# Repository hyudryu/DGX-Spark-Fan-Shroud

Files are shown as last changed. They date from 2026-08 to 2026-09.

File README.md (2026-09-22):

# DGX-Spark-Fan-Shroud

Fan shrouds for NVIDIA GB10 systems, including the NVIDIA DGX Spark and partner platforms, for improved cooling performance on long workloads. Full STL/STEP files, electronics schematics, RP2040 firmware, and the FanController host application provide automatic temperature-based fan control.

The stock cooling on the DGX Spark can thermal-throttle during sustained multi-hour training or inference runs. This project adds a 3D-printed shroud that mounts a high-static-pressure Noctua industrialPPC fan over the heatsink, driven by a closed-loop controller that ramps fan speed with chip temperature — quiet at idle, full airflow under load.

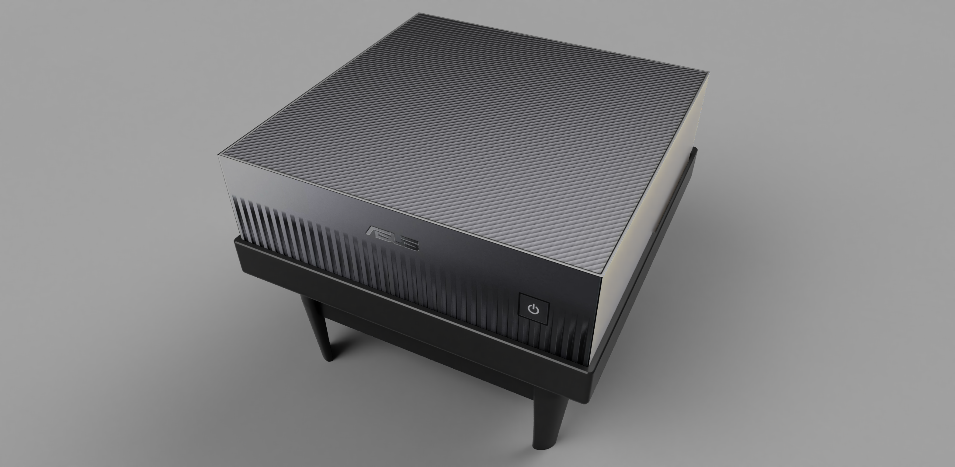
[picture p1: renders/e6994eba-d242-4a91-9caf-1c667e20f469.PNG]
Render of the ASUS Ascent GX10 with the fan shroud and stacking legs installed


## Cooling Results

### ASUS Ascent GX10

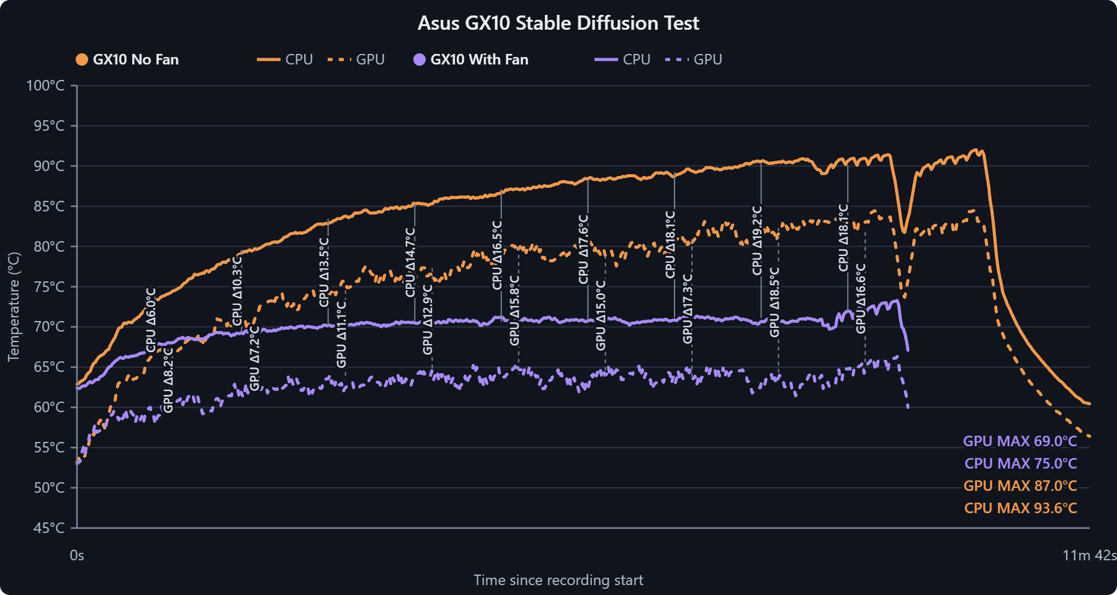
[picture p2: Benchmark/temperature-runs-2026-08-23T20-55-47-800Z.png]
ASUS Ascent GX10 Stable Diffusion temperature comparison with and without the fan shroud


In this roughly 12-minute Stable Diffusion run, the shroud reduced the recorded CPU peak from 93.6 °C to 75.0 °C and the GPU peak from 87.0 °C to 69.0 °C — reductions of 18.6 °C and 18.0 °C, respectively.

### NVIDIA DGX Spark

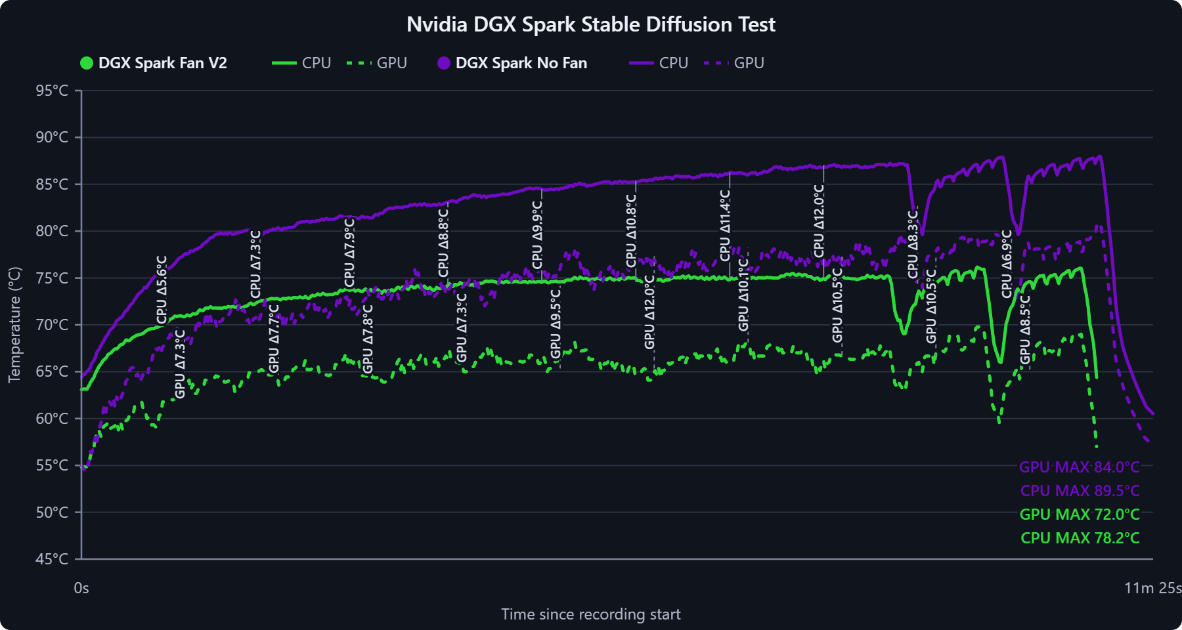
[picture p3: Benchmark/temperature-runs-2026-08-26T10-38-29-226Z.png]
NVIDIA DGX Spark Stable Diffusion temperature comparison with the V2 fan shroud


In this roughly 11-minute Stable Diffusion run, the V2 shroud reduced the recorded CPU peak from 89.5 °C to 78.2 °C and the GPU peak from 84.0 °C to 72.0 °C — reductions of 11.3 °C and 12.0 °C, respectively.

### Findings

The benchmark comparisons show lower CPU and GPU peak temperatures with the fan shroud installed. The ASUS Ascent GX10 result rounds to an approximately 20 °C reduction, while the NVIDIA DGX Spark V2 result and the other platform-specific models are approximately 10 °C reductions. Actual results vary with workload, ambient temperature, print fit, fan, and system vent layout.

| System | CPU peak reduction | GPU peak reduction | Approximate temperature drop |
| --- | ---: | ---: | ---: |
| ASUS Ascent GX10 | 18.6 °C measured | 18.0 °C measured | ~20 °C |
| NVIDIA DGX Spark | 11.3 °C measured | 12.0 °C measured | ~10 °C |
| Gigabyte AI TOP ATOM | ~10 °C | ~10 °C | ~10 °C |
| HP ZGX Nano | ~10 °C | ~10 °C | ~10 °C |
| Lenovo ThinkStation PGX | ~10 °C | ~10 °C | ~10 °C |
| MSI EdgeXpert | ~10 °C | ~10 °C | ~10 °C |

- **Approximately 20 °C lower peak temperatures** on the ASUS Ascent GX10.
- **Approximately 10 °C lower peak temperatures** on the other supported systems.
- Configured to **maintain ~80 °C under normal regular use** via the software fan curve.
- See `Benchmark/` for the interactive thermal benchmark graph and source comparisons.

## Compatibility

> **Compatibility note:** The design has been tested on the **ASUS Ascent GX10** and **NVIDIA DGX Spark**. In the charted tests, the NVIDIA DGX Spark reduction is about half the ASUS result because of its vent layout.
>
> Platform-specific files are also included for the **Gigabyte AI TOP ATOM**, **HP ZGX Nano**, **Lenovo ThinkStation PGX**, and **MSI EdgeXpert**. These variants have different chassis dimensions or vent layouts; verify fit and clearance before printing. Editable STEP files are included for inspection and adaptation.

## Repository Contents

| Path | Description |
| --- | --- |
| `3D Files/Asus Ascent GX10/` | ASUS shroud V2 plus shroud and stacking legs, in print-ready STL and editable STEP formats |
| `3D Files/Gigabyte AI Top Atom/` | Gigabyte fan/front shrouds plus shroud and stacking legs, in STL and STEP formats |
| `3D Files/HP ZGX Nano/` | HP fan/front shrouds plus shroud and stacking legs, in STL and STEP formats |
| `3D Files/Lenovo Thinkstation PGX/` | Lenovo fan/front shrouds plus shroud and stacking legs, in STL and STEP formats |
| `3D Files/MSI EdgeXpert/` | MSI fan/front shrouds plus shroud and stacking legs, in STL and STEP formats |
| `3D Files/Nvidia DGX Spark/` | NVIDIA fan/front shrouds plus shroud and stacking legs, in STL and STEP formats |
| `Benchmark/` | Interactive thermal benchmark graph plus PNG comparisons for quick viewing on GitHub |
| `firmware/` | MicroPython firmware for the RP2040-Zero and X9C103 digital potentiometer |
| `renders/` | Product renders of the shroud installed on supported systems |
| `software/` | FanController host application, systemd service, and tests |

## Bill of Materials

| Part | Purpose | Link |
| --- | --- | --- |
| Noctua industrialPPC fan | High static pressure / airflow through the shroud | https://amzn.to/4gRzM0Q |
| PWM controller | Generates the 25 kHz PWM signal that drives the fan | https://amzn.to/4pzXktr |
| Digital potentiometer | Sets the control voltage on the PWM controller from the microcontroller | https://amzn.to/4ffs8ft |
| RP2040-Zero | Receives host duty commands and drives the digital potentiometer | https://amzn.to/3TepWfD |

*(Links are Amazon affiliate links.)*

You will also need:

- Appropriate DC power for the fan (check your fan's rated voltage — industrialPPC variants are commonly 24 V)
- A USB-C cable capable of **data** transfer (for flashing the RP2040-Zero)
- Soldering iron and hookup wire, plus M3/M4 fasteners for the shroud legs

## How It Works

1. **Sense** — the control software polls the SoC temperature on the Spark (via `nvidia-smi` / tegrastats / hwmon).
2. **Decide** — a fan curve, PID loop, or hysteresis controller maps temperature to a target fan duty cycle.
3. **Actuate** — the firmware sets the digital potentiometer wiper, which drives the analog control input of the PWM controller, which in turn sets the fan's duty cycle.

This keeps the fan curve entirely under software control — you can tune it from a config file or CLI without touching hardware.

## Wiring

The X9C103 digital pot replaces the Owltree controller's onboard B10K potentiometer: remove (or ignore) the onboard pot and wire the X9C103's resistor terminals to its pads.

### RP2040-Zero → X9C103 Digital Pot

```
RP2040-Zero              X9C103 Digital Pot
────────────              ──────────────────
VBUS / 5V  ────────────── VCC
GND        ────────────── GND
GP29       ────────────── INC
GP28       ────────────── U/D
GP27       ────────────── CS
```

### RP2040-Zero → Owltree PWM Controller

```
RP2040-Zero              Owltree PWM Controller
────────────              ───────────────────────
VBUS / 5V  ────────────── VCC
GND        ────────────── GND
```

### Owltree B10K Pot Pads → X9C103

```
Owltree B10K Pot Pads     X9C103
─────────────────────     ──────
Outer pad 1  ──────────── VH
Center/wiper pad ──────── VW
Outer pad 2  ──────────── VL
```

### Full power layout

```
USB-C 5V
   │
   ├── RP2040-Zero VBUS / 5V
   ├── X9C103 VCC
   └── Owltree PWM Controller VCC

USB-C GND
   │
   ├── RP2040-Zero GND
   ├── X9C103 GND
   └── Owltree PWM Controller GND
```

### Full control layout

```
RP2040 GP29 ───────── X9C103 INC
RP2040 GP28 ───────── X9C103 U/D
RP2040 GP27 ───────── X9C103 CS

X9C103 VH ─────────── Owltree outer pot pad
X9C103 VW ─────────── Owltree center/wiper pad
X9C103 VL ─────────── Owltree outer pot pad
```

If the fan speed moves in the **opposite direction** from what the firmware expects, swap `VH` and `VL`. Do not swap the center `VW` connection.

### Important warnings

- **Check the Owltree VCC pad before wiring.** Only connect the Owltree `VCC` pad to `VBUS/5V` after confirming it is the controller's 5 V logic supply. Do **not** connect a 12 V fan-output or 12 V input rail to the RP2040.
- **Logic voltage.** The RP2040 GPIO pins output 3.3 V logic. Some X9C103 modules powered from 5 V may require a control-high voltage above 3.3 V — if the module does not respond reliably, use a 3.3-to-5 V logic-level shifter on `GP29 → INC`, `GP28 → U/D`, and `GP27 → CS`. Never feed 5 V into an RP2040 GPIO pin.
- **Isolate the original pot.** Remove or electrically isolate the Owltree's original B10K potentiometer before wiring the X9C103 to its pads.

## Flashing the RP2040-Zero

The included controller is [MicroPython firmware](firmware/main.py). Install
MicroPython on the RP2040-Zero, then copy the controller to the device as
`main.py` so it starts automatically at boot. See the
[firmware installation guide](firmware/README.md) for exact commands and the
USB serial protocol.

### Optional Arduino X9C103 test sketch

This standalone sketch drives the digital pot to one end stop, then back to
~50%. It can be used with the Arduino IDE to verify wiring before installing
the MicroPython controller:

```cpp
#include <Arduino.h>

constexpr uint8_t PIN_INC = 29;
constexpr uint8_t PIN_UD  = 28;
constexpr uint8_t PIN_CS  = 27;

void pulseIncrement() {
  digitalWrite(PIN_INC, LOW);
  delayMicroseconds(5);
  digitalWrite(PIN_INC, HIGH);
  delayMicroseconds(5);
}

void moveSteps(bool increase, int steps) {
  digitalWrite(PIN_CS, LOW);
  digitalWrite(PIN_UD, increase ? HIGH : LOW);
  delayMicroseconds(5);

  for (int i = 0; i < steps; ++i) {
    pulseIncrement();
  }

  digitalWrite(PIN_CS, HIGH);
  delay(10);
}

void setup() {
  pinMode(PIN_INC, OUTPUT);
  pinMode(PIN_UD, OUTPUT);
  pinMode(PIN_CS, OUTPUT);

  digitalWrite(PIN_INC, HIGH);
  digitalWrite(PIN_UD, LOW);
  digitalWrite(PIN_CS, HIGH);

  delay(1000);

  // Move fully toward the low end.
  moveSteps(false, 110);

  // Move approximately halfway up.
  moveSteps(true, 50);
}

void loop() {
  // Fan remains at the position selected during setup.
}
```

The X9C103 has ~100 positions; sending 110 steps guarantees it reaches the end stop without damage.

### First power-on procedure

1. Power the circuit **without** connecting a fan.
2. Confirm the RP2040 receives ~5 V on `VBUS`.
3. Confirm no RP2040 GPIO pin sees more than 3.3 V.
4. Measure the voltages on the Owltree potentiometer terminals and confirm `VH`, `VW`, and `VL` stay within the X9C103's permitted terminal-voltage range.
5. Connect the fan.
6. Flash the test firmware above and confirm the fan settles at roughly half speed.
7. If the speed direction is reversed, swap `VH` and `VL`.

## 3D Printing

- Choose the folder matching your system before slicing. Every platform folder keeps its print-ready STL and editable STEP files together.
- The revised `Shroud Leg` model is **65 mm tall overall**, 15 mm taller than the previous 50 mm version. Matching STL and STEP versions are included so the printable and editable models stay in sync.

### Recommended print settings

| Setting | Recommendation |
| --- | --- |
| Material | **PLA+ is suitable.** PETG, ASA/ABS, or a PC blend can also be used for greater temperature resistance. |
| Orientation | **Print each leg flat side down.** Keep the shroud in its supplied STL orientation. |
| Supports | **Tree/organic supports enabled** |
| Layer height | 0.2 mm |
| Walls | 4 |
| Infill | 40% or greater for the legs |

The leg (`Shroud Leg.stl`) supports the shroud against the chassis. Place its flat side directly on the build plate before slicing.

## Firmware & Software

The [`firmware/`](firmware/) directory contains the RP2040 digital-pot driver
and serial command interface. It starts at maximum cooling and returns to
maximum cooling if its host heartbeat disappears for five seconds.

The [`software/`](software/) directory contains the FanController application.
It discovers CPU and GPU temperature sensors, provides curve, PID, hysteresis,
and manual modes, and communicates with the firmware using `DUTY 0..255` and
`PING` commands over USB serial. See the
[software installation guide](software/README.md) to install the desktop UI
and headless systemd service.

## License

MIT — see [LICENSE](LICENSE).

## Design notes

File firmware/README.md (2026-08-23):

# Fan controller firmware

`main.py` is the MicroPython firmware for the RP2040-Zero and X9C103 digital
potentiometer described in the repository wiring guide. It accepts fan-duty
commands over the RP2040 USB serial connection and fails safe to maximum
cooling if communication with the host is lost.

## Install

1. Download the latest stable RP2 MicroPython `.uf2` from
   [micropython.org/download/RPI_PICO](https://micropython.org/download/RPI_PICO/).
2. Disconnect the RP2040-Zero, hold its `BOOT`/`BOOTSEL` button, reconnect its
   USB data cable, and release the button when the `RPI-RP2` drive appears.
3. Copy the MicroPython `.uf2` to `RPI-RP2`. The board will reboot and expose a
   USB serial port.
4. Install [mpremote](https://docs.micropython.org/en/latest/reference/mpremote.html)
   on the host and copy the controller program to the board:

   ```bash
   python3 -m pip install --user mpremote
   mpremote connect auto fs cp firmware/main.py :main.py
   mpremote connect auto reset
   ```

Run the `mpremote` commands from the repository root. If more than one
MicroPython device is attached, replace `auto` with the device path, for
example `/dev/ttyACM0`.

On boot, the firmware homes the X9C103 wiper and requests maximum fan speed.
Confirm that `DUTY 255` produces maximum airflow before relying on the
controller. If the direction is reversed, swap `VH` and `VL` as described in
the root wiring guide, or change `MAX_SPEED_AT_HIGH_TAP` in `main.py`.

## USB serial protocol

The USB serial connection uses line-delimited ASCII commands:

| Host command | Firmware response | Meaning |
| --- | --- | --- |
| `DUTY n` | `OK` | Set requested duty, where `n` is `0` through `255` |
| `PING` | `OK` | Keep the five-second safety watchdog alive |
| Invalid command | `ERR ...` | Command was rejected |

The firmware prints `BOOT` after startup and `RPM 0` once per second. RPM is
currently a placeholder because the fan tachometer is not connected.

If no valid `DUTY` or `PING` command arrives for five seconds, the firmware
forces `DUTY 255` until communication resumes.

## Quick serial test

Disconnect any host controller before opening the serial REPL, then run:

```bash
mpremote connect auto repl
```

Press `Ctrl-C` to interrupt `main.py`, then `Ctrl-D` to soft-reset and restart
it. A production host must send `PING` at least once every five seconds; the
FanController host software sends it once per second.

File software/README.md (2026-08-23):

# FanController host software

FanController runs on the DGX Spark, reads the available CPU and NVIDIA GPU
temperature sensors, applies a configurable control algorithm, and sends fan
duty commands to the RP2040 firmware over USB serial.

It provides:

- A GTK configuration and monitoring interface
- Curve, PID, hysteresis, and manual control modes
- CPU hwmon and `nvidia-smi` temperature discovery
- Temperature smoothing and duty slew limiting
- A headless systemd user service
- A mock serial device for configuration and testing without hardware
- Fail-safe maximum duty when no usable temperature is available

## Install

Flash the [RP2040 firmware](../firmware/README.md) first. Then, from this
directory, run:

```bash
./setup.sh
```

The setup script installs the GTK and serial dependencies, gives the current
user access to serial devices through the `dialout` group, installs the
application launcher, and enables the headless user service. Log out and back
in if the script adds you to `dialout`.

To install without enabling the service:

```bash
./setup.sh --no-enable
```

## Configure and run

Open the configuration interface from the desktop application menu or run:

```bash
python3 -m fancontroller --ui-only
```

Select the RP2040 serial port (normally `/dev/ttyACM0`), choose one or more
temperature sources, configure the desired control mode, and save. The
headless daemon reloads configuration changes automatically.

Useful commands:

```bash
python3 -m fancontroller --check
systemctl --user start fancontroller
systemctl --user status fancontroller
journalctl --user-unit fancontroller -f
```

Settings are stored in `~/.config/fancontroller/config.json`. Runtime state is
published atomically to `$XDG_STATE_HOME/fancontroller/state.json`, or
`~/.local/state/fancontroller/state.json` when `XDG_STATE_HOME` is unset.
This local state file is optional integration data; the controller does not
require a dashboard, server, network connection, or any other application.

## Test

The unit tests use only the Python standard library:

```bash
python3 -m unittest discover -s tests -v
```

The test suite covers active-mode settings, external temperature controls,
and Linux hwmon sensor discovery. Hardware and GTK behavior require an
on-device smoke test.

## Layout

| Path | Description |
| --- | --- |
| `fancontroller/` | Host application, daemon, control algorithms, sensors, and serial link |
| `packaging/` | systemd user service and desktop launcher |
| `tests/` | Host-side unit tests |

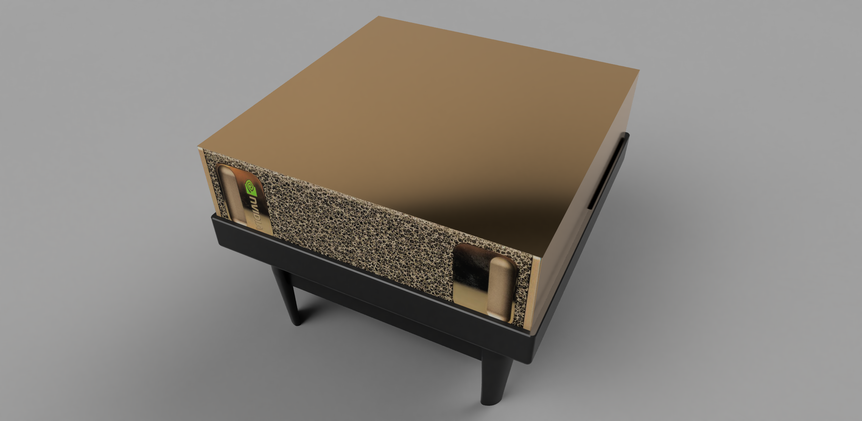
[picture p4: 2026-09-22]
renders/56fdb077-9e4b-4a9a-adc3-96f7fca2e5fc.PNG

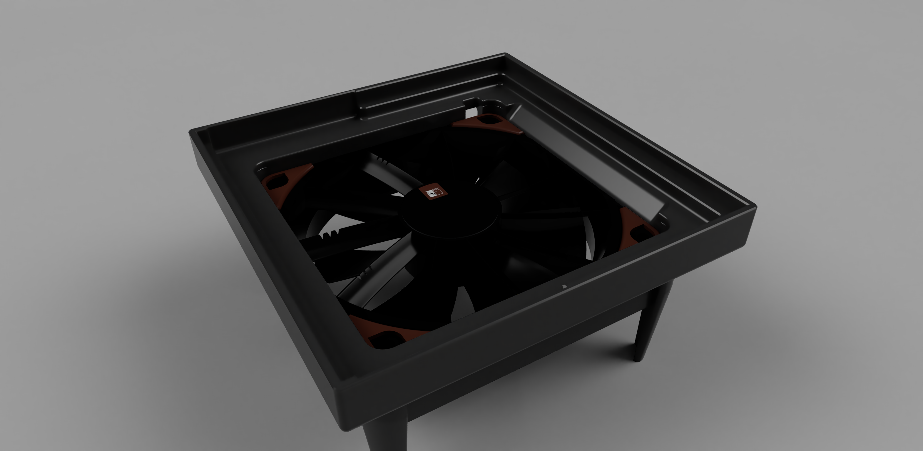
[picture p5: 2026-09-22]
renders/c32153a5-907a-47e3-8001-998e51b5a0a1.PNG

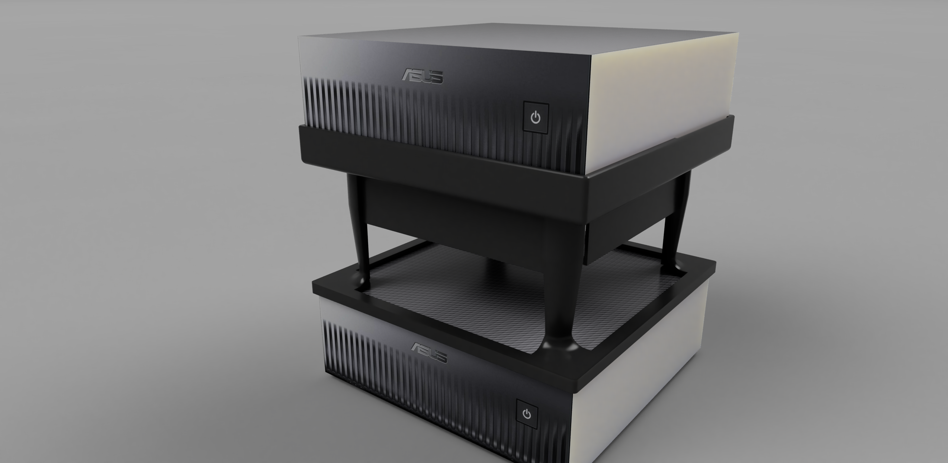
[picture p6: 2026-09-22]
renders/GX10_Fan_2026-Aug-24_03-08-53AM-000_CustomizedView17884324747.png

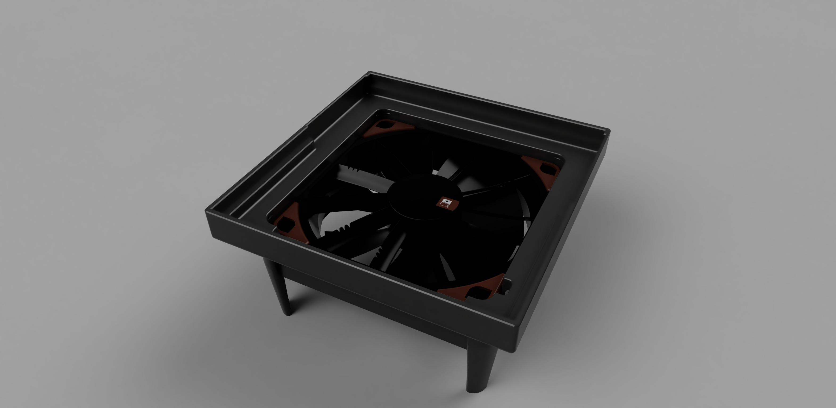
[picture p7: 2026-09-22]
renders/69367214-8b8e-4549-86d5-82fe3ee90c81.PNG

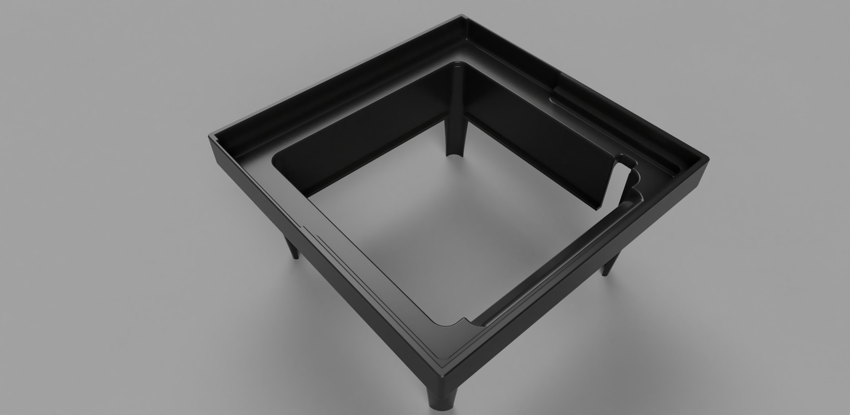
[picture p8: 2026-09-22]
renders/51bbc9f1-16c5-4712-b1a2-3e77c67671fc.PNG

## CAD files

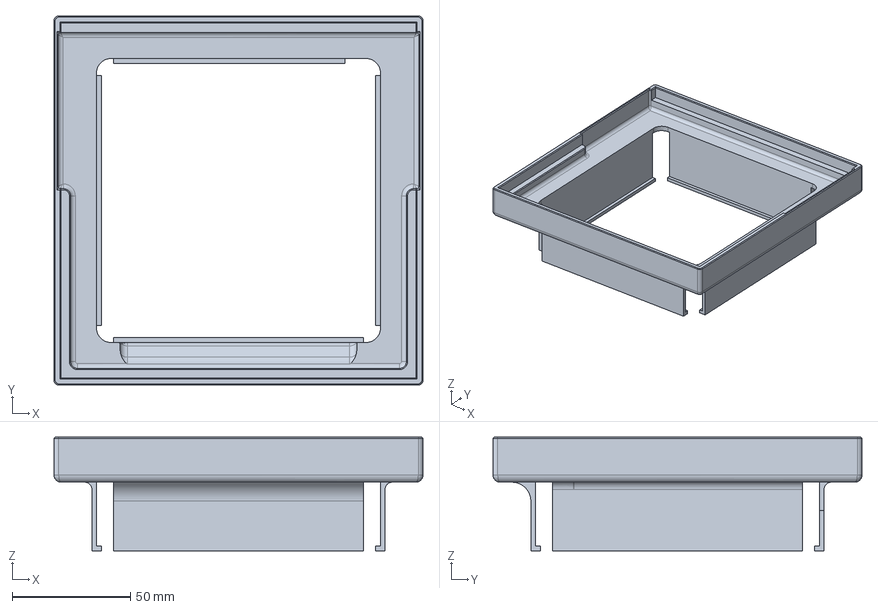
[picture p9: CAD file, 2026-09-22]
3D Files/Asus Ascent GX10/GX10 Shroud V2.step
156.0 x 156.0 x 48.0 mm

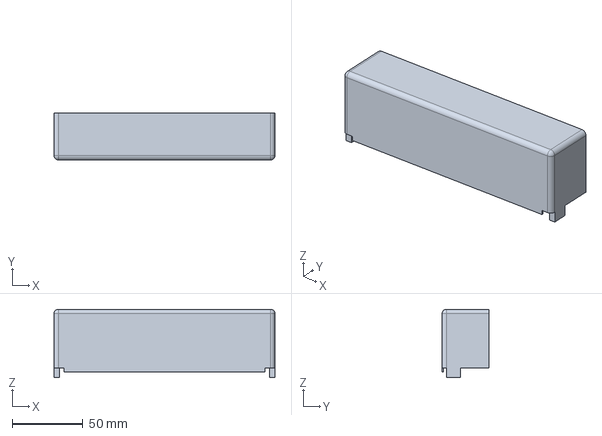
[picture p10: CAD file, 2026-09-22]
3D Files/Gigabyte AI Top Atom/Gigabyte Front Shroud.step
156.0 x 33.0 x 48.3 mm

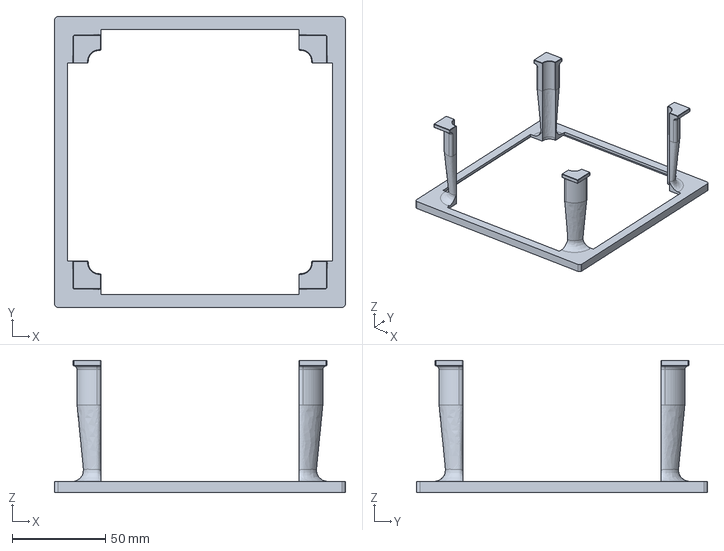
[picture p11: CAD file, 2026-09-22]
3D Files/HP ZGX Nano/Stacking Legs.step
156.0 x 156.0 x 71.0 mm

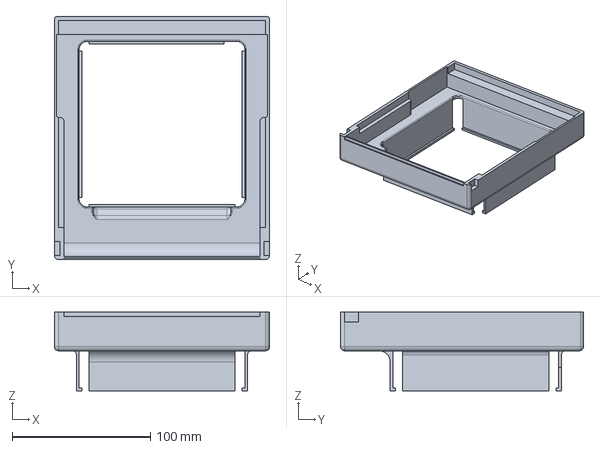
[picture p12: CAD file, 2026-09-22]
3D Files/Lenovo Thinkstation PGX/Lenovo Fan Shroud.step
156.0 x 176.0 x 57.0 mm

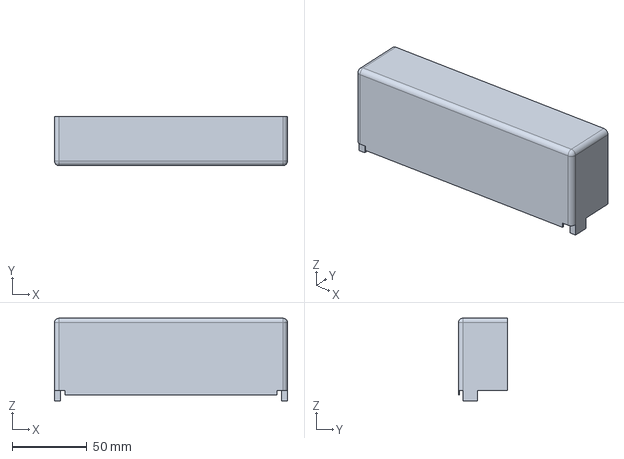
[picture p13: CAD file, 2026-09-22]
3D Files/MSI EdgeXpert/MSI Front Shroud.step
156.0 x 33.0 x 55.3 mm

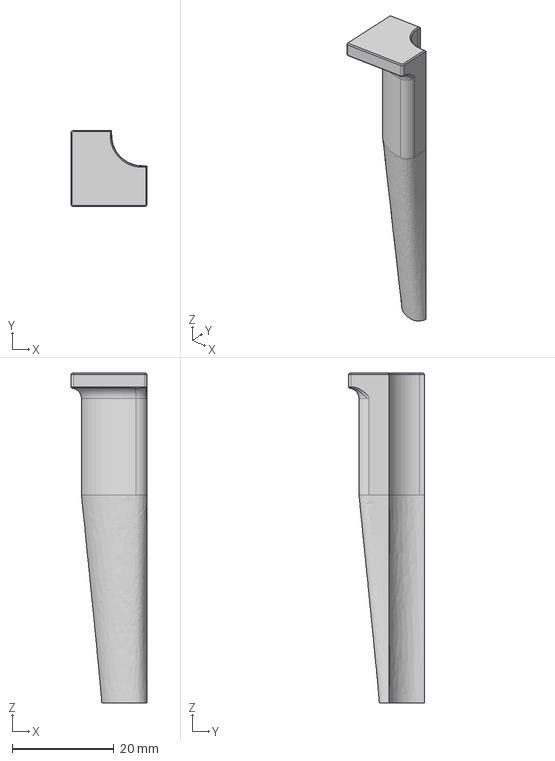
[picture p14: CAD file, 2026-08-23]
3D Files/Asus Ascent GX10/Shroud Leg.step
15.0 x 15.0 x 65.0 mm

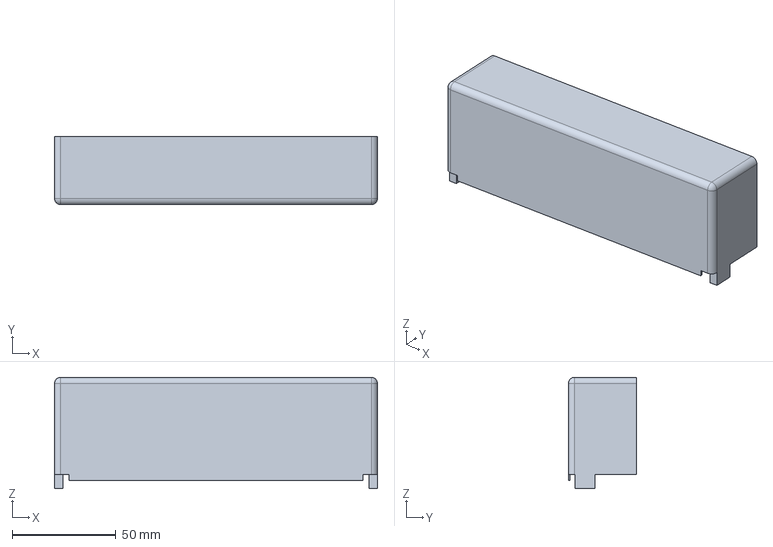
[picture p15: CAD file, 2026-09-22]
3D Files/HP ZGX Nano/HP Front Shroud.step
156.0 x 33.0 x 53.8 mm

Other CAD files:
3D Files/Asus Ascent GX10/GX10 Shroud V2.stl
3D Files/Asus Ascent GX10/Shroud Leg.stl
3D Files/Asus Ascent GX10/Stacking Legs.stl
3D Files/Gigabyte AI Top Atom/Gigabyte Fan Shroud.stl
3D Files/Gigabyte AI Top Atom/Gigabyte Front Shroud.stl
3D Files/Gigabyte AI Top Atom/Shroud Leg.stl
3D Files/Gigabyte AI Top Atom/Stacking Legs.stl
3D Files/HP ZGX Nano/HP Fan Shroud.stl
3D Files/HP ZGX Nano/HP Front Shroud.stl
3D Files/HP ZGX Nano/Shroud Leg.stl
3D Files/HP ZGX Nano/Stacking Legs.stl
3D Files/Lenovo Thinkstation PGX/Lenovo Fan Shroud.stl
3D Files/Lenovo Thinkstation PGX/Lenovo Front Shroud.stl
3D Files/Lenovo Thinkstation PGX/Shroud Leg.stl
3D Files/Lenovo Thinkstation PGX/Stacking Legs.stl
3D Files/MSI EdgeXpert/MSI Fan Shroud.stl
3D Files/MSI EdgeXpert/MSI Front Shroud.stl
3D Files/MSI EdgeXpert/Shroud Leg.stl
3D Files/MSI EdgeXpert/Stacking Legs.stl
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

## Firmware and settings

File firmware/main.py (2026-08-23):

# RP2040-Zero MicroPython firmware for an OwlTree fan controller using an
# X9C103 10K digital potentiometer.
#
# Wiring:
#   X9C103 VCC -> RP2040 5V
#   X9C103 GND -> RP2040 GND
#   X9C103 INC -> RP2040 GP29
#   X9C103 U/D -> RP2040 GP28
#   X9C103 CS  -> RP2040 GP27
#
#   X9C103 VH -> one outside OwlTree B10K pad
#   X9C103 VW -> center OwlTree B10K pad
#   X9C103 VL -> other outside OwlTree B10K pad
#
# Serial protocol:
#   DUTY 0..255
#   PING
#
# DUTY 0   = minimum requested fan speed
# DUTY 255 = maximum requested fan speed
#
# Watchdog:
#   No valid command for WATCHDOG_S seconds forces DUTY 255.

import select
import sys
import time
from machine import Pin


# ---------------------------------------------------------------------
# Pin configuration
# ---------------------------------------------------------------------

INC_PIN = 29
UD_PIN = 28
CS_PIN = 27

WATCHDOG_S = 5
RPM_PERIOD_MS = 1000
X9C_POWERUP_SETTLE_MS = 100
X9C_ENDPOINT_STEPS = 100

# After flashing, DUTY 255 should produce maximum fan speed and DUTY 0 should
# produce minimum fan speed. If operation is reversed, change this value.
MAX_SPEED_AT_HIGH_TAP = False


# ---------------------------------------------------------------------
# X9C103 setup
# ---------------------------------------------------------------------

inc = Pin(INC_PIN, Pin.OUT, value=1)
ud = Pin(UD_PIN, Pin.OUT, value=0)
cs = Pin(CS_PIN, Pin.OUT, value=1)

current_tap = 0


def move_wiper(up, steps):
    """Move the X9C103 by a specified number of positions.

    The X9C103 moves on each HIGH-to-LOW transition of INC while CS is LOW.
    INC is kept LOW when CS rises so the position is not written to the
    X9C103's nonvolatile memory each time.
    """
    steps = int(steps)

    if steps <= 0:
        return

    if steps > 100:
        steps = 100

    # INC must begin HIGH.
    inc.value(1)

    # U/D must settle before the first INC falling edge.
    ud.value(1 if up else 0)
    time.sleep_us(5)

    # Select the digital potentiometer.
    cs.value(0)
    time.sleep_us(5)

    for step in range(steps):
        # Falling edge moves the wiper one position.
        inc.value(0)
        time.sleep_us(5)

        # Raise INC for the next falling edge, except after the final step.
        # Leaving it LOW prevents an EEPROM store when CS rises.
        if step < steps - 1:
            inc.value(1)
            time.sleep_us(5)

    # Deselect while INC is LOW: no nonvolatile-memory write.
    cs.value(1)
    time.sleep_us(5)

    # Restore the normal idle state.
    inc.value(1)


def home_wiper_low():
    """Establish a known starting position.

    The X9C103 does not wrap around at its endpoints, so sending 100 downward
    steps guarantees that it reaches tap zero.
    """
    global current_tap

    move_wiper(False, X9C_ENDPOINT_STEPS)
    current_tap = 0


def set_tap(target, force_endpoint=False):
    """Set the X9C103 to a tap position from 0 through 99.

    ``current_tap`` is only a software estimate: the X9C103 has no position
    feedback. A power glitch or missed INC edge can therefore leave the
    physical wiper somewhere other than the remembered tap. When an endpoint
    is requested, optionally send a full sweep even if the estimate already
    says that it is there. The X9C103 stops at its endpoints, so this safely
    restores a known physical position.
    """
    global current_tap

    target = int(target)

    if target < 0:
        target = 0
    elif target > 99:
        target = 99

    if force_endpoint and (target == 0 or target == 99):
        move_wiper(target == 99, X9C_ENDPOINT_STEPS)
        current_tap = target
        return

    if target > current_tap:
        move_wiper(True, target - current_tap)
    elif target < current_tap:
        move_wiper(False, current_tap - target)

    current_tap = target


def set_duty_byte(duty):
    """Convert the 0..255 DUTY command to one of the X9C103's 100 taps."""
    duty = int(duty)

    if duty < 0:
        duty = 0
    elif duty > 255:
        duty = 255

    logical_tap = round(duty * 99 / 255)

    if MAX_SPEED_AT_HIGH_TAP:
        target_tap = logical_tap
    else:
        target_tap = 99 - logical_tap

    # Exact 0% and 100% commands are synchronization points. Do not trust
    # current_tap at an endpoint: physically drive the wiper against the
    # requested stop so a reset or missed pulse cannot leave the fan at the
    # opposite speed.
    set_tap(target_tap, force_endpoint=(duty == 0 or duty == 255))


# ---------------------------------------------------------------------
# Safe startup
# ---------------------------------------------------------------------

# Allow the X9C103 supply and control inputs to settle before the first INC
# edges. The RP2040 and potentiometer are powered together, and pulses sent
# too early can be ignored while the potentiometer is still starting up.
time.sleep_ms(X9C_POWERUP_SETTLE_MS)

# Find a known endpoint first.
home_wiper_low()

# Full cooling until the host begins sending commands.
set_duty_byte(255)

print("BOOT")


# ---------------------------------------------------------------------
# Serial command loop
# ---------------------------------------------------------------------

last_cmd_ms = time.ticks_ms()
last_rpm_ms = time.ticks_ms()
watchdog_active = False
buf = ""

poll = select.poll()
poll.register(sys.stdin, select.POLLIN)

while True:
    if poll.poll(0):
        ch = sys.stdin.read(1)

        if ch:
            if ch == "\n" or ch == "\r":
                line = buf.strip()
                buf = ""

                if line.startswith("DUTY"):
                    parts = line.split()

                    if len(parts) == 2:
                        try:
                            duty = int(parts[1])

                            if duty < 0 or duty > 255:
                                print("ERR duty-range")
                            else:
                                set_duty_byte(duty)
                                last_cmd_ms = time.ticks_ms()
                                watchdog_active = False
                                print("OK")

                        except ValueError:
                            print("ERR bad-duty")
                    else:
                        print("ERR bad-duty")

                elif line == "PING":
                    last_cmd_ms = time.ticks_ms()
                    watchdog_active = False
                    print("OK")

                elif line == "":
                    pass

                else:
                    print("ERR unknown")

            else:
                buf += ch

                if len(buf) > 64:
                    buf = ""
                    print("ERR line-too-long")

    now = time.ticks_ms()

    # Loss of communication forces maximum cooling.
    if time.ticks_diff(now, last_cmd_ms) > WATCHDOG_S * 1000:
        if not watchdog_active:
            set_duty_byte(255)
            watchdog_active = True

    # Tach remains disconnected.
    if time.ticks_diff(now, last_rpm_ms) >= RPM_PERIOD_MS:
        last_rpm_ms = now
        print("RPM", 0)

    time.sleep_ms(2)

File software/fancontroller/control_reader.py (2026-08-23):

"""Read optional, short-lived control overrides from external tools.

An external tool can drop a JSON file at
``~/.local/state/fancontroller/control.json``. ``max_speed`` forces 100% duty,
while ``temperature_override`` supplies an expiring external sensor reading.
The latter is combined with local sensors using ``max()`` so an external tool
can never make the fan run cooler than local telemetry requires. FanController
works normally when this file is absent.
"""
from __future__ import annotations

import json
import math
import os
import time
from dataclasses import dataclass
from pathlib import Path


CONTROL_DIR = Path(os.environ.get("XDG_STATE_HOME") or os.path.expanduser("~/.local/state")) / "fancontroller"
CONTROL_PATH = CONTROL_DIR / "control.json"

@dataclass(frozen=True)
class ExternalControl:
    max_speed: bool = False
    temperature_c: float | None = None
    source: str | None = None
    node_id: str | None = None
    node_name: str | None = None
    observed_at: float | None = None
    expires_at: float | None = None


_cached_data: dict[str, object] | None = None
_cached_mtime: float | None = None


def _number(value: object) -> float | None:
    if isinstance(value, bool) or not isinstance(value, (int, float)):
        return None
    result = float(value)
    return result if math.isfinite(result) else None


def read_control(now: float | None = None) -> ExternalControl:
    """Return validated, currently active external control inputs.

    Results are cached keyed on the file's mtime so we don't hit disk on
    every poll tick. Expiry is evaluated on every call even when cached.
    """
    global _cached_data, _cached_mtime
    try:
        mtime = CONTROL_PATH.stat().st_mtime_ns
    except OSError:
        _cached_data = None
        _cached_mtime = None
        return ExternalControl()
    if _cached_mtime != mtime:
        try:
            raw = json.loads(CONTROL_PATH.read_text(encoding="utf-8"))
            _cached_data = raw if isinstance(raw, dict) else None
        except Exception:
            _cached_data = None
        _cached_mtime = mtime

    data = _cached_data or {}
    result = ExternalControl(max_speed=bool(data.get("max_speed", False)))
    override = data.get("temperature_override")
    if not isinstance(override, dict):
        return result
    temperature_c = _number(override.get("temperature_c"))
    expires_at = _number(override.get("expires_at"))
    current_time = time.time() if now is None else float(now)
    if (temperature_c is None or temperature_c < -40 or temperature_c > 150
            or expires_at is None or expires_at < current_time):
        return result

    def text(key: str) -> str | None:
        value = override.get(key)
        return value if isinstance(value, str) and value else None

    return ExternalControl(
        max_speed=result.max_speed,
        temperature_c=temperature_c,
        source=text("source"),
        node_id=text("node_id"),
        node_name=text("node_name"),
        observed_at=_number(override.get("observed_at")),
        expires_at=expires_at,
    )


def effective_temperature(
    local_temperature_c: float | None,
    control: ExternalControl,
) -> float | None:
    """Use the hottest valid local or external temperature."""
    temperatures = [
        value for value in (local_temperature_c, control.temperature_c)
        if value is not None
    ]
    return max(temperatures) if temperatures else None


def read_max_speed() -> bool:
    """Backward-compatible helper for max-speed-only integrations."""
    return read_control().max_speed


def clear_max_speed() -> None:
    """Clear max speed without discarding unrelated external controls."""
    global _cached_data, _cached_mtime
    try:
        raw = json.loads(CONTROL_PATH.read_text(encoding="utf-8"))
        data = raw if isinstance(raw, dict) else {}
        data.pop("max_speed", None)
        if data:
            tmp = CONTROL_PATH.with_suffix(".json.tmp")
            tmp.write_text(json.dumps(data), encoding="utf-8")
            os.replace(tmp, CONTROL_PATH)
        else:
            CONTROL_PATH.unlink(missing_ok=True)
    except (OSError, json.JSONDecodeError):
        pass
    _cached_data = None
    _cached_mtime = None

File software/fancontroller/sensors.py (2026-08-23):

"""Temperature sources for the fan controllers."""
from __future__ import annotations

import logging
import subprocess
from pathlib import Path
from typing import Optional

log = logging.getLogger(__name__)


class TempSource:
    def __init__(self, key: str, label: str) -> None:
        self.key = key
        self.label = label

    def read(self) -> Optional[float]:
        raise NotImplementedError


class CpuTempSource(TempSource):
    """Read the hottest CPU/package temperature exposed by Linux hwmon."""

    # Names used by the common x86, ARM, and firmware-backed CPU sensors.
    # acpitz is included because some ARM systems expose their SoC/CPU thermal
    # zones only through ACPI rather than a CPU-specific hwmon driver.
    HWMON_NAMES = {
        "acpitz",
        "coretemp",
        "cpu_thermal",
        "cpu-thermal",
        "k10temp",
        "soc_thermal",
        "soc-thermal",
        "zenpower",
    }

    def __init__(self, inputs: list[Path]) -> None:
        super().__init__("cpu", "CPU (Linux hwmon)")
        self.inputs = inputs

    @classmethod
    def discover(
        cls, hwmon_root: Path = Path("/sys/class/hwmon")
    ) -> Optional["CpuTempSource"]:
        inputs: list[Path] = []
        try:
            devices = sorted(hwmon_root.glob("hwmon*"))
        except OSError:
            return None
        for device in devices:
            try:
                name = (device / "name").read_text().strip().lower()
            except OSError:
                continue
            if name not in cls.HWMON_NAMES:
                continue
            inputs.extend(sorted(device.glob("temp*_input")))
        source = cls(inputs)
        return source if source.read() is not None else None

    def read(self) -> Optional[float]:
        temps: list[float] = []
        for path in self.inputs:
            try:
                # The hwmon ABI reports temperatures in millidegrees Celsius.
                value = float(path.read_text().strip()) / 1000.0
            except (OSError, ValueError):
                continue
            # Ignore disconnected/broken sensor values while retaining a wide
            # enough range for valid readings during startup and shutdown.
            if -20.0 <= value <= 150.0:
                temps.append(value)
        return max(temps) if temps else None


class NvidiaSmiSource(TempSource):
    def __init__(self) -> None:
        super().__init__("gpu", "GPU (nvidia-smi)")

    def read(self) -> Optional[float]:
        try:
            out = subprocess.run(
                [
                    "nvidia-smi",
                    "--query-gpu=temperature.gpu",
                    "--format=csv,noheader,nounits",
                ],
                capture_output=True,
                text=True,
                timeout=2,
            )
        except (subprocess.SubprocessError, FileNotFoundError):
            return None
        if out.returncode != 0:
            return None
        temps: list[float] = []
        for line in out.stdout.splitlines():
            line = line.strip()
            if not line:
                continue
            try:
                temps.append(float(line))
            except ValueError:
                log.warning("ignoring non-numeric nvidia-smi output: %r", line)
        return max(temps) if temps else None


def discover() -> list[TempSource]:
    """Discover available temperature sources.

    CPU is listed first so it is preferred when a configuration has no valid
    selected source. Returns an empty list if no sources are available.
    """
    sources: list[TempSource] = []
    cpu = CpuTempSource.discover()
    if cpu is not None:
        sources.append(cpu)
    nv = NvidiaSmiSource()
    if nv.read() is not None:
        sources.append(nv)
    return sources


def aggregate_max(sources: list[TempSource]) -> Optional[float]:
    vals = [v for v in (s.read() for s in sources) if v is not None]
    return max(vals) if vals else None

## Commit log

2026-07-22 Add STL/STEP files, thermal benchmark, and expand README
    - Add print-ready STL and editable STEP files for the GX10 shroud and leg
    - Add interactive cooling benchmark graph
    - README: BOM with Noctua industrialPPC fan, PWM controller, digital
    potentiometer, and RP2040-Zero; control-loop overview; performance
    results (~20C cooler under max load, ~80C maintained under normal use)
    [GX10 Leg.step, GX10 Shroud Leg.stl, GX10 Shroud.step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]
2026-07-22 Add wiring schematic and ASUS GX10 compatibility disclaimer
    - Full wiring diagrams: RP2040-Zero to X9C103 digital pot and Owltree
    PWM controller, pot-pad mapping, power and control layouts
    - Note the design is only tested on ASUS Ascent GX10; other DGX Spark
    variants (NVIDIA/MSI/Gigabyte) will need the STEP files revised to fit
2026-07-22 Add RP2040-Zero flashing instructions and updated shroud files
    - Flashing guide: UF2 drag-and-drop and Arduino IDE (arduino-pico)
    - Basic X9C103 test firmware sketch and first power-on checklist
    - Wiring warnings: 3.3V logic-level note, VH/VL swap fix, isolate
    the original B10K pot, verify Owltree VCC is the 5V logic rail
    - Updated GX10 Shroud STL/STEP files
    [GX10 Shroud.step, GX10 Shroud.stl]
2026-08-22 Replace GX10 3D files with renamed DGX Spark versions and update README
    [DGX Spark Shroud.step, DGX Spark Shroud.stl, GX10 Leg.step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]
2026-08-23 Update shroud leg and document thermal benchmarks
    [Shroud Leg.step, Shroud Leg.stl]
2026-08-23 Clarify shroud leg revision notes
2026-08-23 Correct overall shroud leg height
2026-08-26 Refresh platform-specific 3D models
    [DGX Fan Shroud.step, DGX Fan Shroud.stl, DGX Front Shroud.step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]
2026-08-26 Update benchmark results and temperature drops
